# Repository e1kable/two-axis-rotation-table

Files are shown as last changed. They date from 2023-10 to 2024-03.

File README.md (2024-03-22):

# Two-Axis Rotation Table

Welcome to the Two-Axis Rotation Table project! This open-source project focuses on the development of a versatile rotation system, featuring azimuth and elevation axes. The table is driven by two powerful NEMA-17 motors, providing precise control and flexibility for various applications.

<p align="middle">
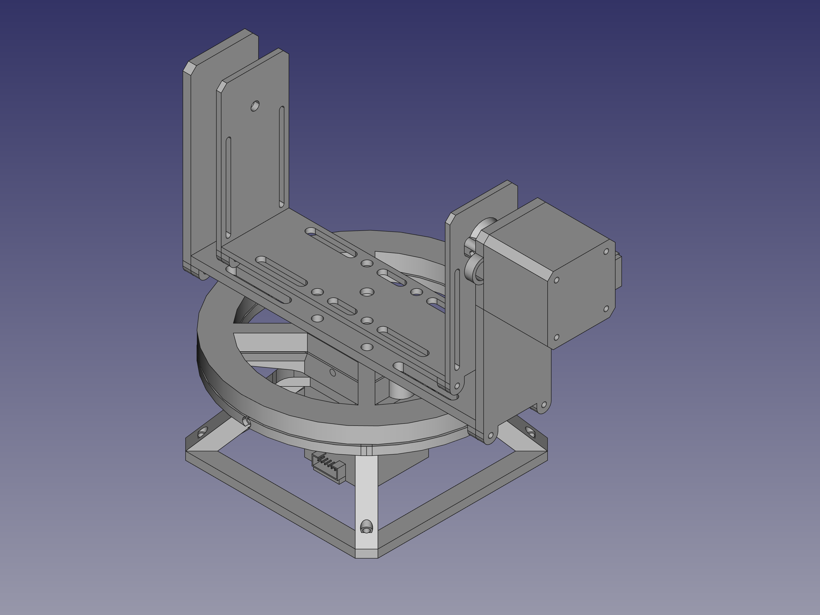
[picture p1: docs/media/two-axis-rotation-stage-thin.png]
Two-Axis Rotation Table
    
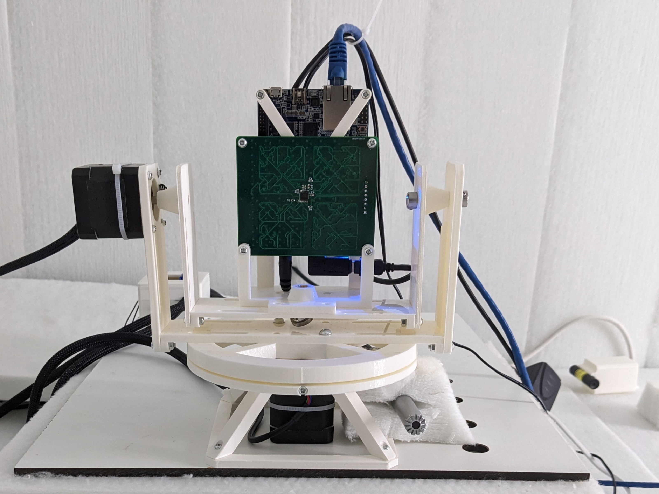
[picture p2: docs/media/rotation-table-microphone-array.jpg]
Built table with Microphone Array
     
    Left: The CAD model of the Two-Axis Rotation Table. Right: The assembeld table with a microphone array on the experiment carrier.
</p>

Other names: Rotational Actuator, Pan-and-Tilt Rotational Stage, Elevation-Azimuth Positioner.

## Key Features

- **Dual Axes:** The rotation table boasts two axes – azimuth and elevation, allowing for multidimensional positioning.
- **NEMA-17 Motors:** Powered by robust NEMA-17 stepper motors, ensuring reliable and accurate rotation.
- **Magnetic Referencing:** Accurate axis referencing is achieved through the use of magnets and Hall sensors, providing a reliable and repeatable starting point.
- **Arduino MCU and CNC Shield:** The electronics are built upon the Arduino R4 Minima microcontroller unit (MCU) and a CNC shield, offering a user-friendly and customizable platform for control.

## Use Cases

This rotation table is ideal for various applications, including:

### Antenna Measurement

Achieve precise orientation for antenna measurements, enabling accurate testing and characterization of radiation patterns.

### Microphone Array Measurements

Optimize the positioning of microphone arrays for audio capture, facilitating the study of sound localization and enhancing beamforming performance.

## Getting Started

To get started with your own rotation table, check out the documentation in the `design-files` directory. There you'll find the FreeCAD design files which can be exported to .stl files for 3-D printing. The project is split into three larger components:

1. Azimuth rotation stage (`design-files/azimuth-rotation-table.FCStd`)
2. Elevation rotation stage (`design-files/elevation-rotation-table.FCStd`)
3. Housing for the Arduino (`design-files/electronics-housing.FCStd`)

Each file consists of serveral parts, which can be separately exported and printed.

## Repository Structure

- `/docs`: Detailed documentation on assembly, wiring, and programming.
- `/design-files`: CAD drawings and design files for the rotation table.
- `/src`: Arduino code for controlling the rotation table.
- `/hardware`: Schematics and board layouts for the CNC shield.

Feel free to contribute, report issues, or explore customization options. Happy rotating!

### Python Library
There exists a python library to control the rotation table. It can be found under: https://github.com/e1kable/pyrotlib .
<!--video src="docs/media/rotation-table-demo.mp4" controls title="Rotation Table Demo"></video-->

## Acknowledgement
This project was partly funded by the Federal Ministry of Economic Affais and Climate Action under grant FKZ: 03EE3066D Verbundvorhaben LoCA.

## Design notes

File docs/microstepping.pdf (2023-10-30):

### CNC Arduino Shield

We will be using the Protoneer CNC Shield for the exercises and projects in the course utilizing stepper motors. This board attaches to an Arduino Uno and carries three Pololu A4988 stepper motor drivers.

Contents

CNC Arduino Shield

Arduino Installation
Driver Installation
Current Limiting
NEMA17 Stepper Motor
Arduino Pin Assignments
CNC Shield Circuit Diagram CNC Shield Component Layout Microstepping Setup
Fourth Axis Setup

Arduino Installation

The CNC Shield should be installed on an Arduino Uno as shown in the following image:

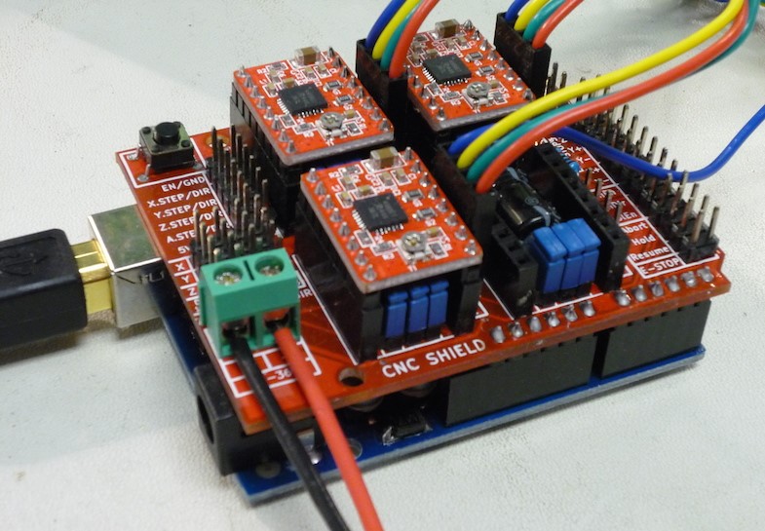
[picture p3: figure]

CNC Shield board installed on top of an Arduino Uno.

Note that the shield board has four fewer pins than socket positions on the Arduino; be sure that A4, A5, D0, and D1 are connected and the board outlines line up.

Driver Installation

The drivers should be installed in the locations and orientations as shown in the following image:

CNC Arduino Shield — Kinetic Fabrics | https://courses.ideate.cmu.edu/16-376/s2020/ref/text/hardware/cnc-shi...
1 von 5 | 06.10.2023, 10:42

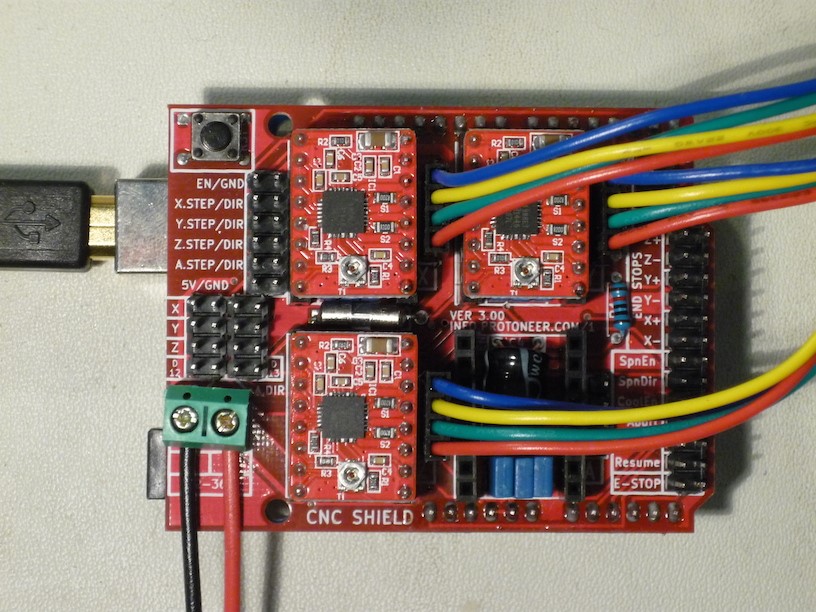
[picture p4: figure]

Top view of CNC Shield showing USB cable, power leads, A4988 drivers, and motor leads.

Please carefully note the polarity of the motor supply wiring at the lower left of the image; these should be connected to a 12V power supply. Please be extra careful not to attach a 12V supply to the 5V Mini Maestro which we also use.

The colored wires to the right are the stepper motor leads for the KL17H248-15-4A. Either connector orientation works, although this particular orientation is recommended for consistency, with blue toward the top.

Note that each driver has a potentiometer adjustment for the current limit; this must be set as described below.

Current Limiting

The A4988 actively limits the current flowing through each stepper motor coil according to the setting of the current limit potentiometer and the active microstepping phase. This allows a supply voltage substantially higher than the rated motor voltage, increasing step rate performance.

The current limit must be set correctly for the particular motor installed on the driver. It is most easily configured by measuring the voltage on the wiper of each reference potentiometer while using a tiny screwdriver to adjust it. The wiper pin is in the center of the edge located toward the inside of the board. The 5V logic power must applied to the CNC shield, normally by making sure the Arduino is powered via USB. The correct reference voltage is as follows:

VREF = I_max / 2.5 For example, the preferred KL17H248-15-4A NEMA17 stepper motor has a rated current of 1.5 A, so the correct VREF = 1.5A / 2.5 = 0.6V. NEMA17 Stepper Motor

We are using the KL17H248-15-4A NEMA17 stepper motor with the CNC Shield. This is a bipolar 200 counts/rev 1.5A/phase stepper motor in a square NEMA17 package. The shaft is 5 mm diameter with a flat, the mounting screws are M3 located on a 31 mm square.

Drawing: cnc-images/KL17H248-15-4A.pdf

Arduino Pin Assignments

2 von 5 | 06.10.2023, 10:42

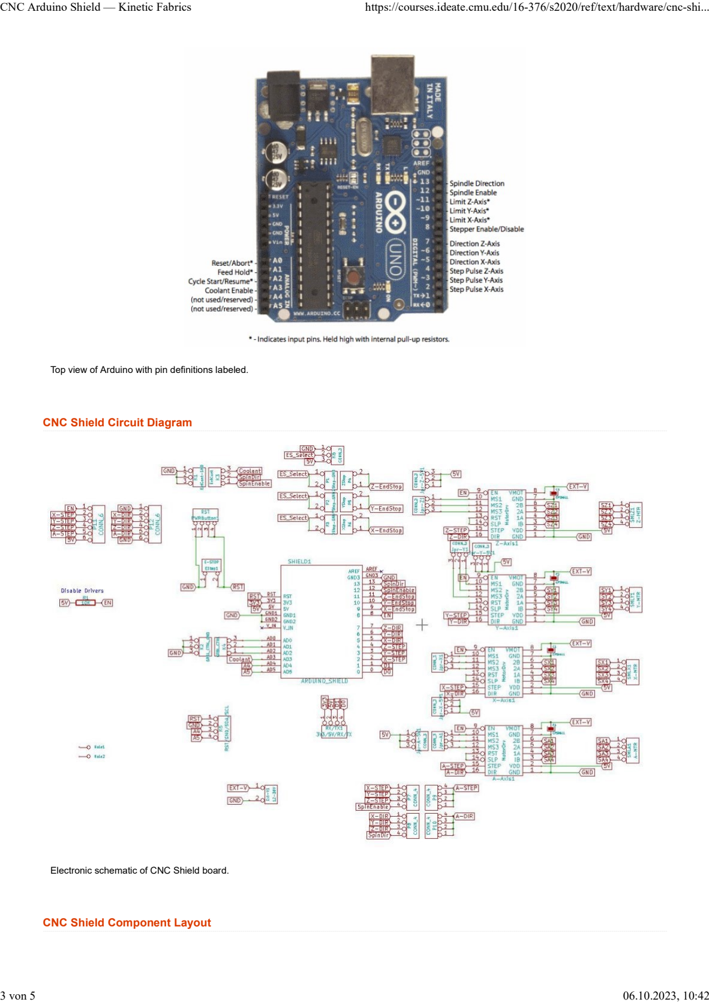
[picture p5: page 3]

Top view of Arduino with pin definitions labeled.

CNC Shield Circuit Diagram

Electronic schematic of CNC Shield board.

CNC Shield Component Layout

3 von 5 | 06.10.2023, 10:42

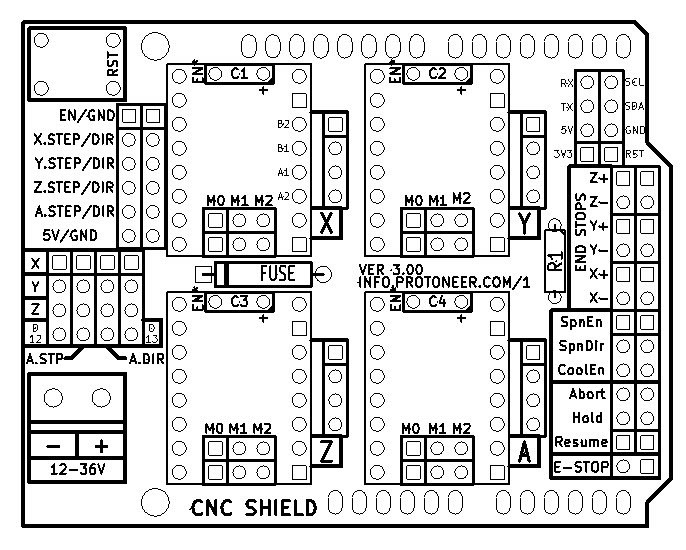
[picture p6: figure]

Top silkscreen of CNC Shield board.

Microstepping Setup

The A4988 is capable of microstepping at 2X, 4X, 8X, or 16X the full-step resolution, configured using pull-up jumpers located beneath each driver module on the CNC Shield board; please refer to the positions labeled M0, M1, or M2, in the image above.

With no jumpers installed each step pulse is a full motor step; with all three each step pulse is 1/16 of a motor step, trading off speed for accuracy. The full configurations are as follows:

M0 | M1 M2 Microstep Resolution
No | No No Full step
Yes No No Half step
No Yes No Quarter step
Yes Yes No Eighth step
Yes Yes Yes Sixteenth step

Anecdotally, using our NEMA17 stepper motors unloaded but without any acceleration control, the maximum speed at full step is around 4 rev/second (800 steps/second). At 4X microstepping, this appears to improve slightly to around 5 rev/sec (4000 steps/sec), and the noise is reduced. This can be further improved by limiting the acceleration so the velocity profile ramps up, allowing the motor inertia to keep up with the changing magnetic fields.

Fourth Axis Setup

The shield supports a fourth “A Axis” driver which may be configured using jumpers to mirror any of X, Y, or Z, or it may operate independently. In independent operation it uses D12 for A-STEP and D13 for A-DIR, precluding use of these pins as SpinDir or SpinEnable.

4 von 5 | 06.10.2023, 10:42

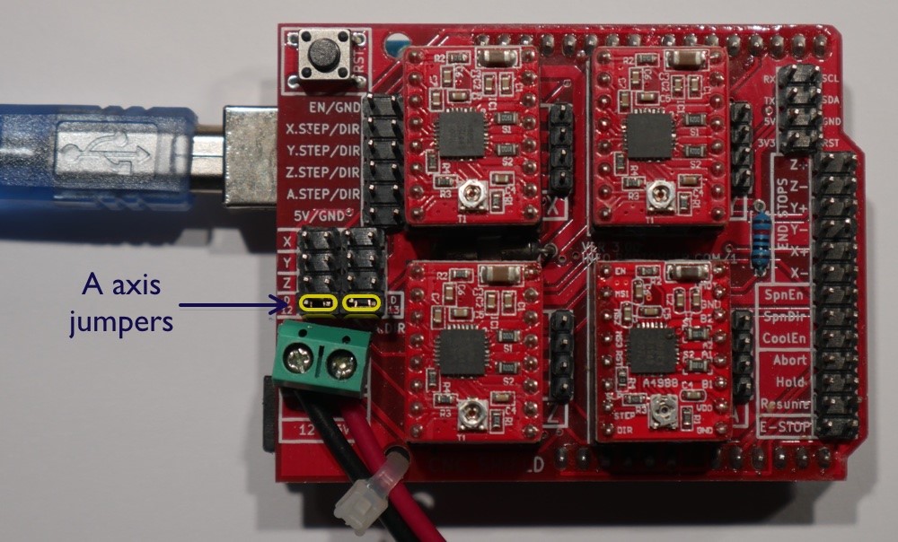
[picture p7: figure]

Configuration for four independent axes. Jumpers are installed at the two positions marked in yellow. The fourth driver is installed in the lower right socket.

5 von 5 | 06.10.2023, 10:42

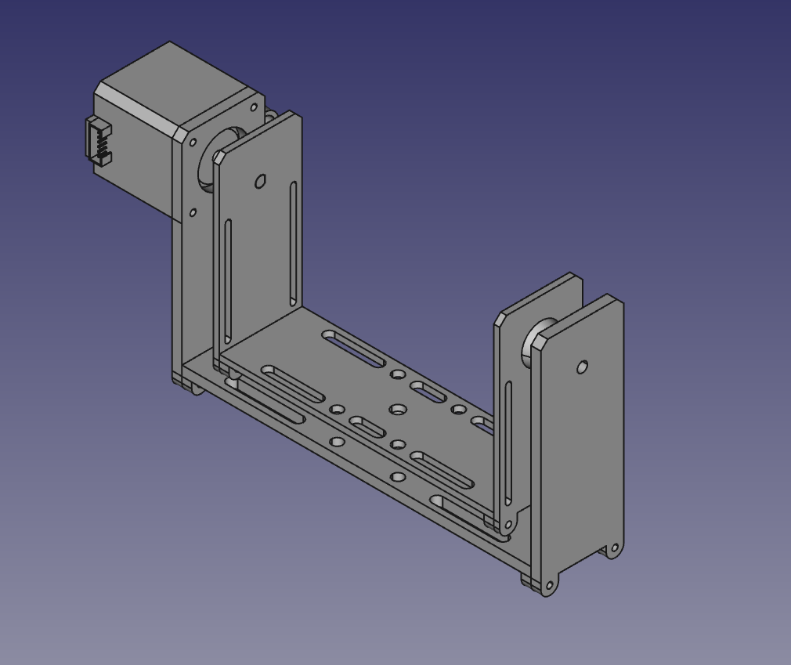
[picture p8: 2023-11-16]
docs/media/elevation-stage.png

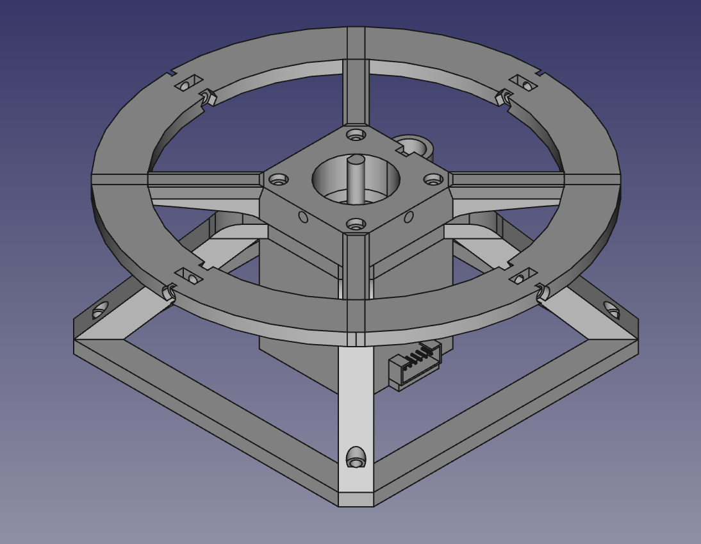
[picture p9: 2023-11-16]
docs/media/azimuth-stage.png

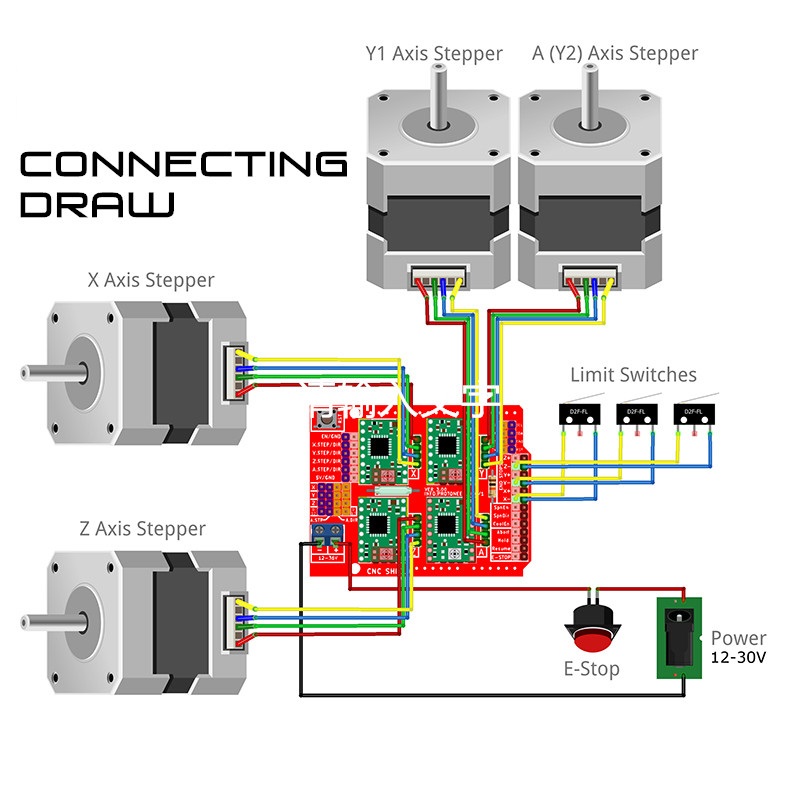
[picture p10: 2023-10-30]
docs/cnc-shield-connection-plan.jpg

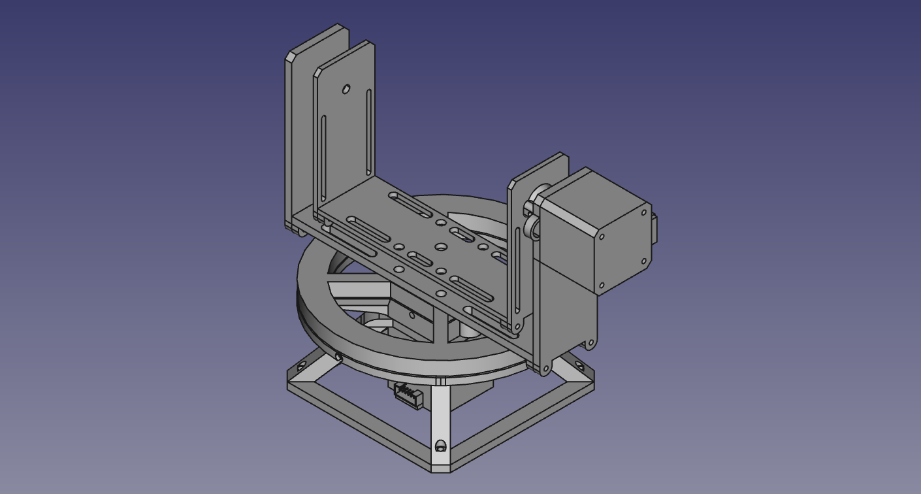
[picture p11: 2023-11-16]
docs/media/two-axis-rotation-stage.png

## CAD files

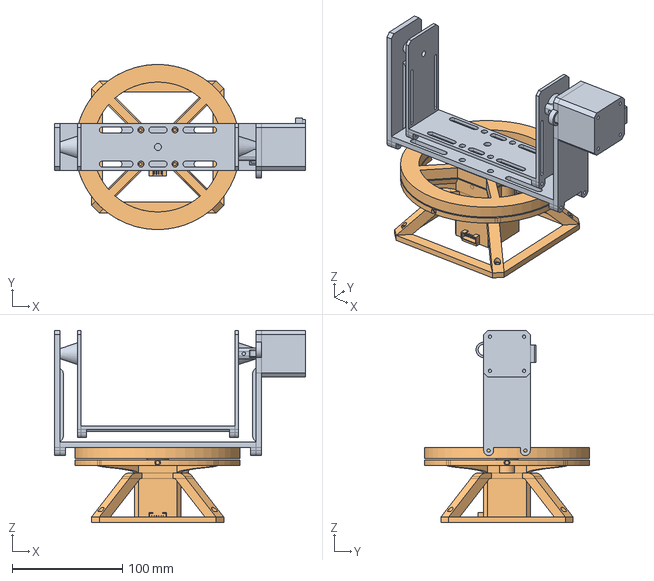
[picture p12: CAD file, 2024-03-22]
design-files/2-axis-rotation-table-fused.FCStd
228.0 x 150.0 x 174.6 mm

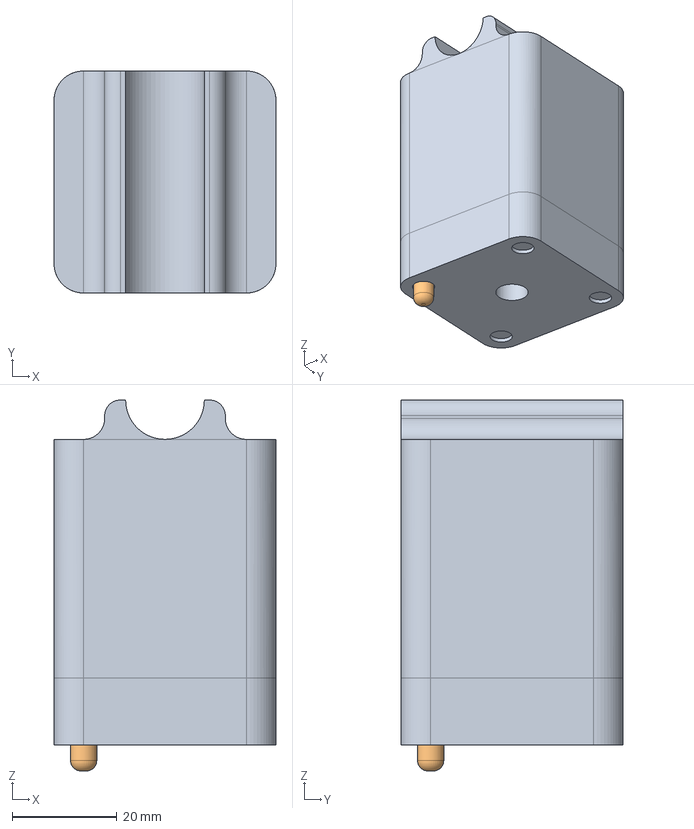
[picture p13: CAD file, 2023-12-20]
design-files/laser-mount-mk-2.FCStd
42.3 x 42.3 x 70.7 mm
Mount
Feet

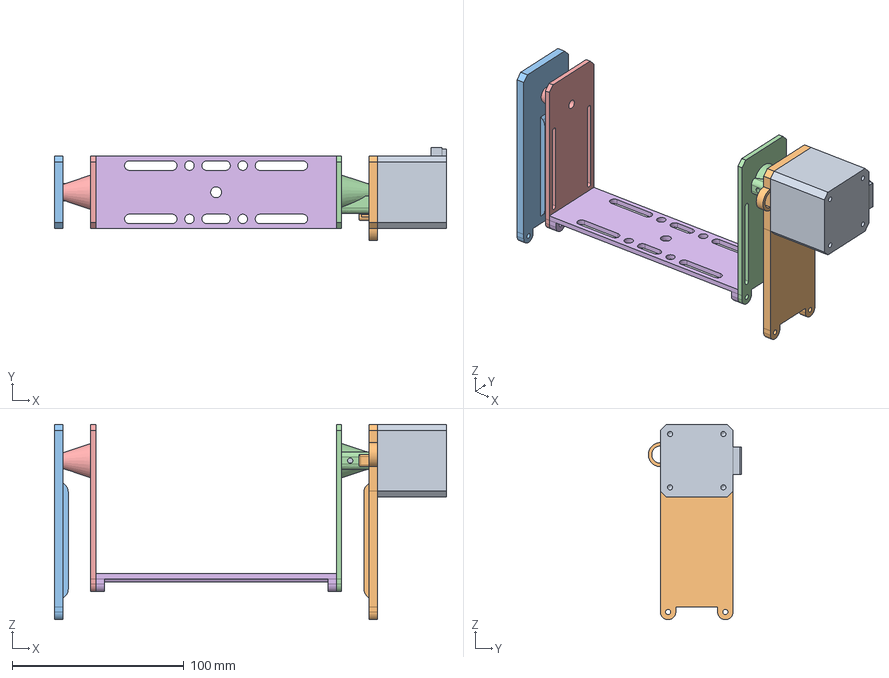
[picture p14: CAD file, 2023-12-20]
design-files/elevation-rotation-table-mk-2.FCStd
228.0 x 54.3 x 113.7 mm
Motor
Static-Handle-1
Static-Handle-2
Rot-Handle-1
Rot-Handle-2
Rot-Bridge

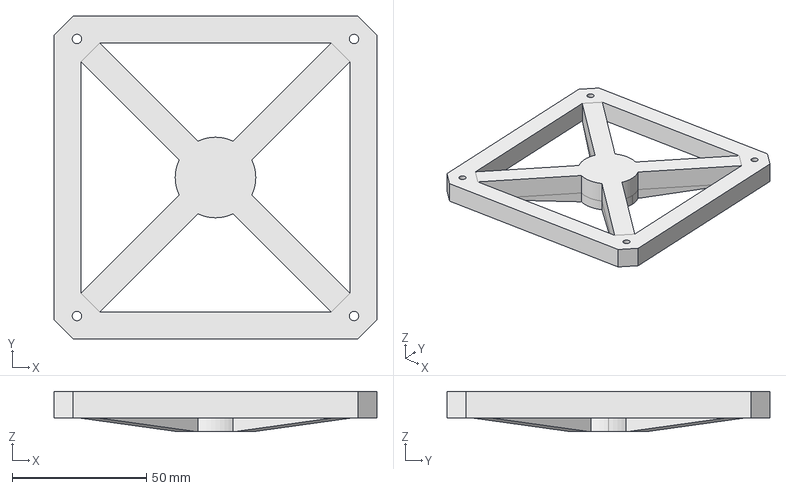
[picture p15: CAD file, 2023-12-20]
design-files/tripod-mount.FCStd
120.2 x 120.2 x 15.0 mm

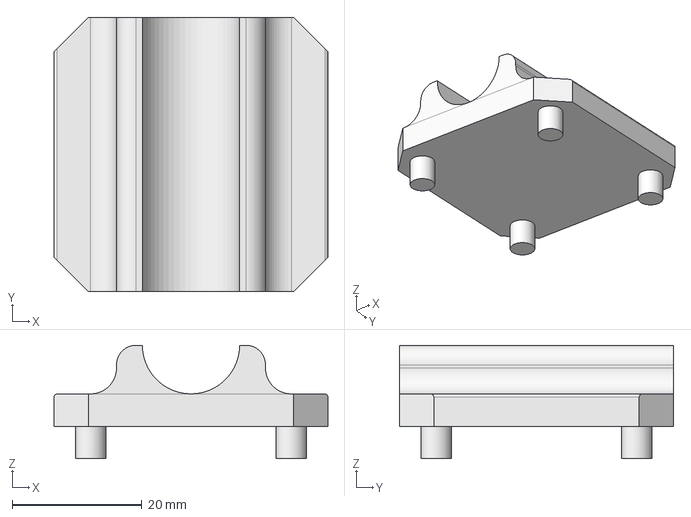
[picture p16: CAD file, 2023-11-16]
design-files/laser-mount.FCStd
42.3 x 42.3 x 17.5 mm

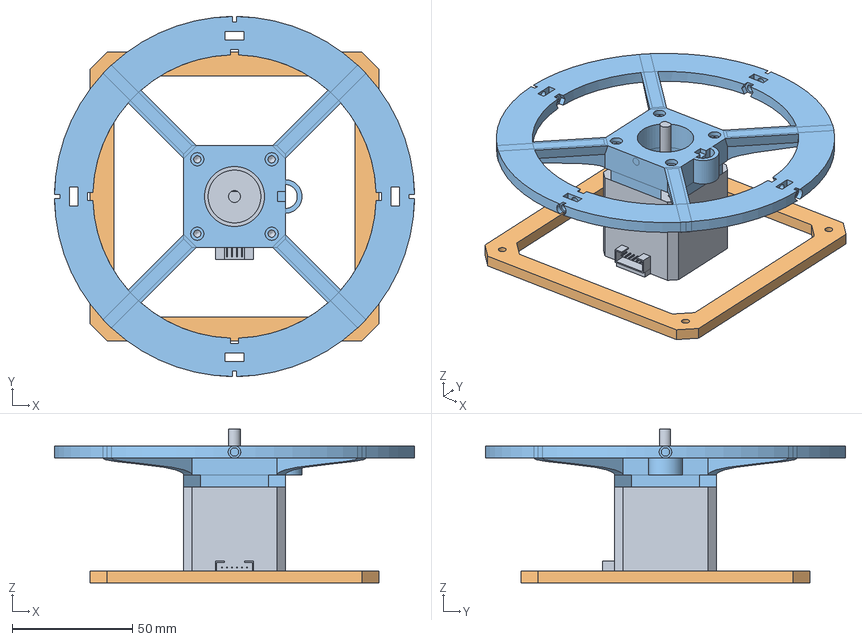
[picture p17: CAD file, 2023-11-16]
design-files/azimuth-rotation-table.FCStd
150.0 x 150.0 x 64.0 mm
NEMA-17-Motor-4401
Base-Ring
Base-Motor-Connector

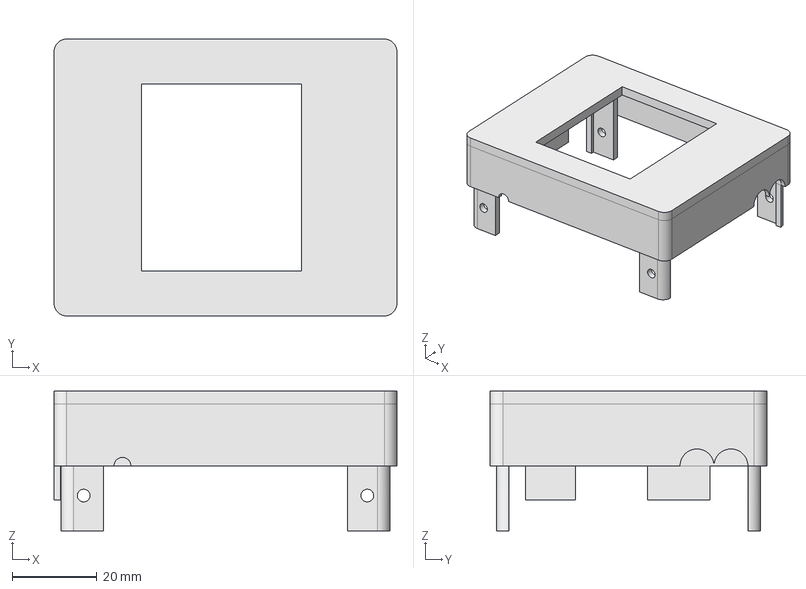
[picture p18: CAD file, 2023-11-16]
design-files/electronics-housing.FCStd
80.9 x 65.3 x 33.0 mm

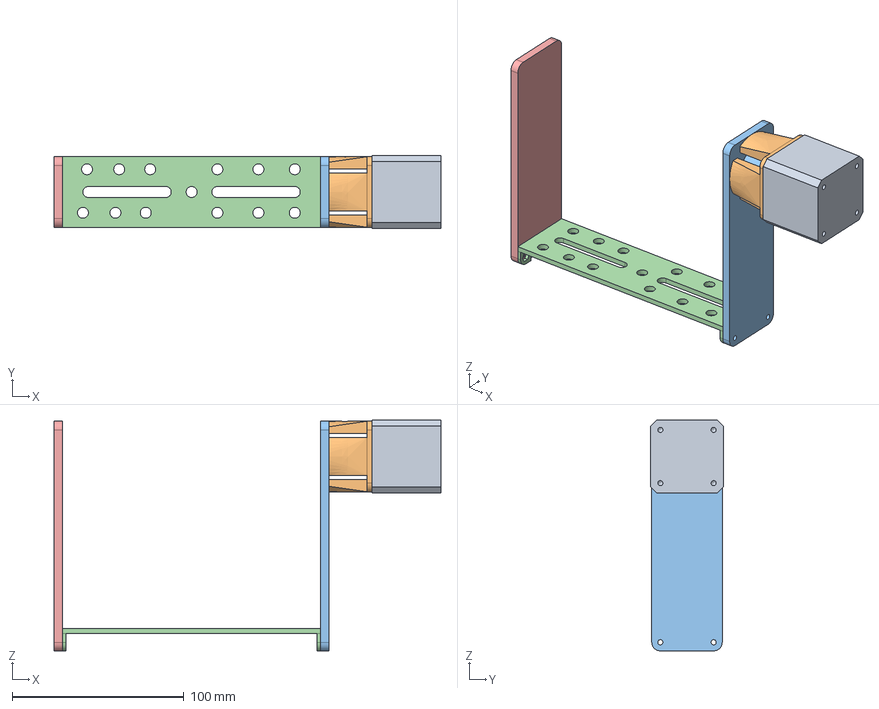
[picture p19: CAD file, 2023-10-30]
design-files/elevation-rotation-table.FCStd
225.0 x 42.3 x 134.2 mm
Motor NEMA17
Motor-Table-connector
Handle-Motor-Arm-1
Bridge
Handle-Arm-2

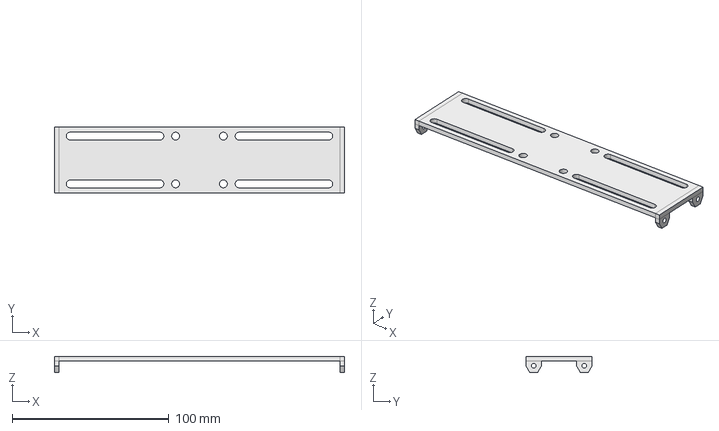
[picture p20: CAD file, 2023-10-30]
design-files/elevation-rotation-table-save.FCStd
185.0 x 42.3 x 10.3 mm

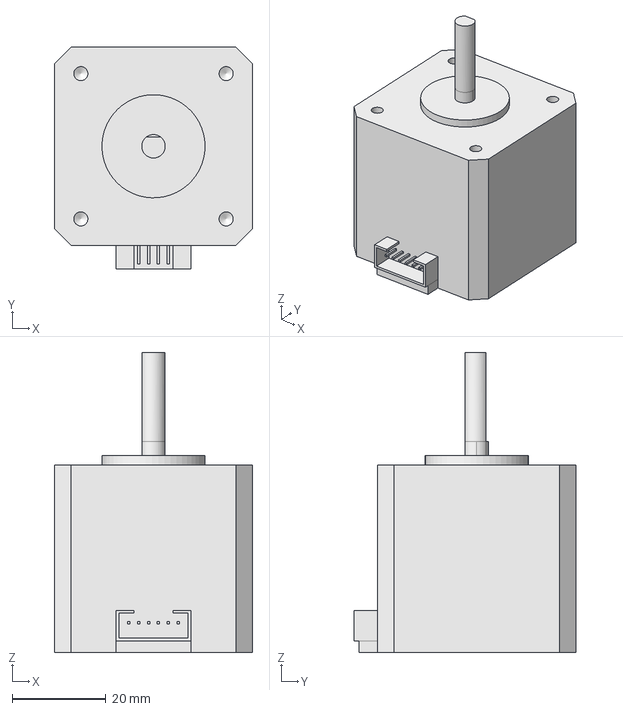
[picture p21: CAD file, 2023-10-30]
design-files/NEMA-17-Motor-4401.FCStd
42.3 x 47.3 x 64.0 mm

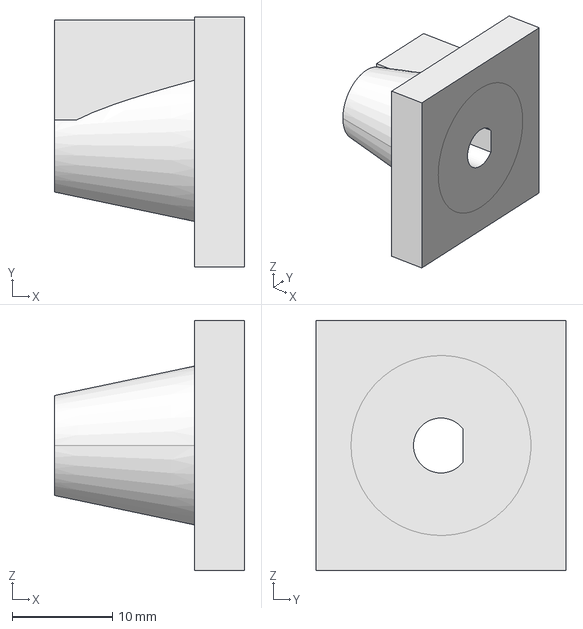
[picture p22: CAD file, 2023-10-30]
design-files/motor-fitting-test.FCStd
19.0 x 25.0 x 25.0 mm

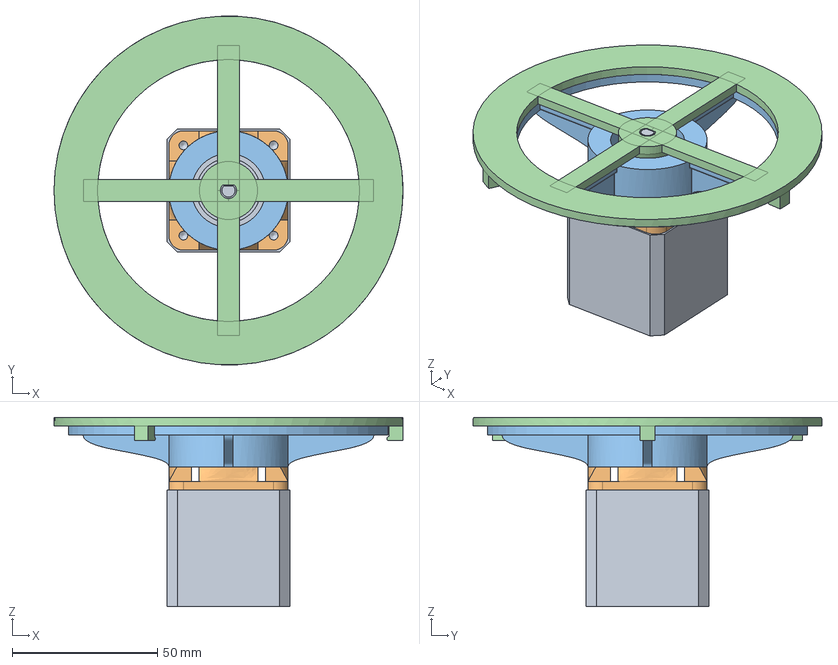
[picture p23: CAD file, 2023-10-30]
design-files/2-axis-rotation-table.FCStd
120.0 x 119.9 x 65.0 mm
Motor NEMA17
Motor-Table-connector
Table-Stator-1
Table-Rotor-1

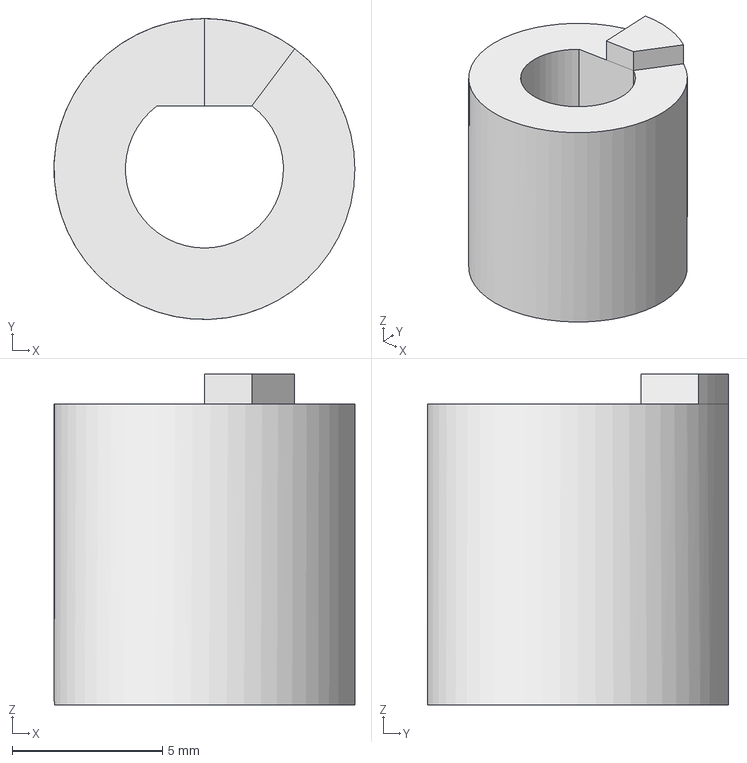
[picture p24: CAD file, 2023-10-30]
design-files/fittings-test.FCStd
10.00 x 10.00 x 11.0 mm

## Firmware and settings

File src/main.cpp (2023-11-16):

#include <Arduino.h>

#ifdef ARDUINO_AVR_UNO
#include <ArduinoSTL.h>
#endif

#include "common.h"
#include "comm.h"
#include "reference.h"

using namespace std;

void setup()
{
  while (!Serial)
    ;

  Serial.begin(SERIAL_BAUD);
  Serial.println(CMD_OK.c_str());
}

void loop()
{
  parseSerialCommands();
}

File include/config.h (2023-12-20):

#ifndef ROT_TABLE_CONFIG_H
#define ROT_TABLE_CONFIG_H

// Axis configuration
#define N_STEPS_AZ 200
#define N_MICRO_STEPS_AZ 16
#define MAX_DPHI_DT_AZ 40.0

#define N_STEPS_EL 200
#define N_MICRO_STEPS_EL 16
#define MAX_DPHI_DT_EL 40.0

// Hall and Referencing configuration
#define REFERENCE_ANGULAR_VELOCITY 5

#ifdef ARDUINO_ARCH_RENESAS_UNO
#define N_MEAN_DEFAULT_HALL_READOUT 1000
#define N_MEAN_DEFAULT_HALL_FINE_READOUT 6000
#endif

#ifdef ARDUINO_AVR_UNO
#define N_MEAN_DEFAULT_HALL_READOUT 100
#define N_MEAN_DEFAULT_HALL_FINE_READOUT 400
#endif

#define DB_DPHI_THRES 10
#define REFERENCE_OFFSET_CORRECTION_AZ -3.8  // in degrees
#define REFERENCE_OFFSET_CORRECTION_EL -11.5 // in degrees
#define REFERENCE_MAGNET_SIZE_DEG 20.0       // in degrees
#define REFERENCE_MOVING_AVG_FILT_SIZE 5

// Slope config
#define IS_ENABLE_SLOPING 1
#define T_SLOPE 1.0                // in s; time until MAX_DPHI_DT_xx is reached
#define SLOPING_MAX_SLEEP_TIME 150 // in ms

#define SERIAL_BAUD 115200

#endif

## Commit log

2023-10-30 Added design files
    [2-axis-rotation-table-fused.FCStd, 2-axis-rotation-table.FCStd, NEMA-17-Motor-4401.FCStd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]
2023-10-31 Added command to read the hall sensor Fixed bug where referencing failed silently at the end
    [comm.cpp, config.h, reference.cpp]
2023-11-16 - Added project README.md - Added support for the Arduino R4 Minima - updated the cad drawings
    [azimuth-rotation-table.FCStd, electronics-housing.FCStd, elevation-rotation-table-mk-2.FCStd]
2023-11-16 - Update Readme with demovideo - tuned the calibration settings
2023-11-16 - Changed the reference to normalize for step size - Changed the db/dphi threshold - updated some CAD designs
    [laser-mount-mk-2.FCStd, laser-mount.FCStd]
2023-12-20 - Added two point referencing - changed the default config values (also to 16 microsteps, better with TMC2208 driver) - Changed README.md
    [elevation-rotation-table-mk-2.FCStd, laser-mount-mk-2.FCStd, tripod-mount.FCStd]
2024-03-22 Updated fused table model
    [2-axis-rotation-table-fused.FCStd]
